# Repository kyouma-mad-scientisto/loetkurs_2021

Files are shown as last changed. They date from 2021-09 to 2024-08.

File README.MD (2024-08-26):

Dieses kleine Badge habe ich 2021 für einen Lötkurs an meiner Hochschule entworfen. Damit sollten die Teilnehmer SMD löten üben. Am Ende konnten sie ihr Werk mit nach Hause nehmen und nach belieben programmieren.
Anlässlich des Girl's Days habe ich in einer späteren Iteration noch einen CH340 ergänzt, damit der Controller ohne extra Hardware programmiert werden kann, es wird nur noch ein Mini-USB Kabel benötigt.

FuldAIno vorn<br />
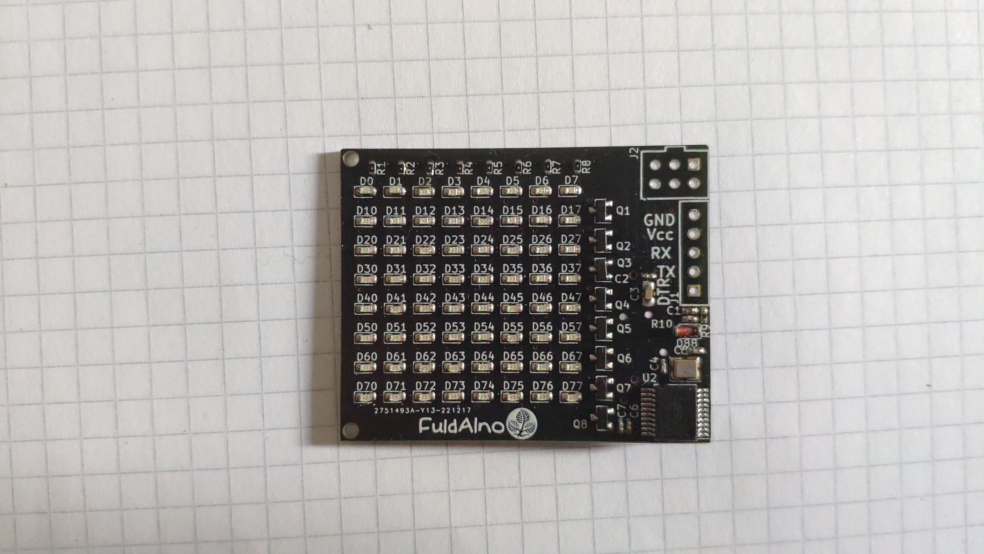
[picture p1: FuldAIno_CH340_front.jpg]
FuldAIno_front


FuldAIno hinten<br />
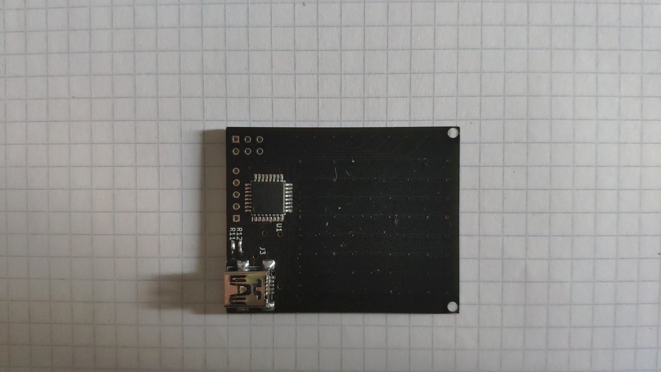
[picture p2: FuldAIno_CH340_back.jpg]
FuldAIno_back


FuldAIno im Betrieb<br />
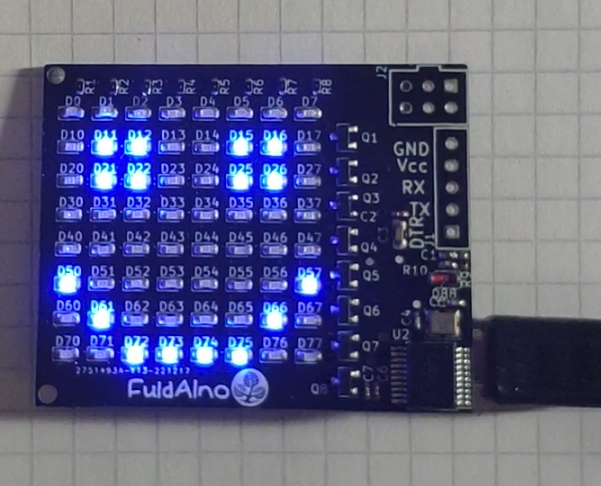
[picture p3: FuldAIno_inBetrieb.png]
FuldAIno_running


IM WEITEREN FOLGT DIE ORIGINALE README.md
###########################################################################################################################################################################################################################

FuldAIno - eine 8x8 LED Matrix gesteuert von einem Atmega328p

Soll FuldAIno nach dem bestücken der Leiterplatte Arduino kompatibel sein, muss zunächst mit einem AVR ISP Flasher, über den 6 pol. ISP Anschluss, der Bootloader auf den Atmega328p gebrannt werden.
Den passenden Bootloader bzw. die passende Bibliothek für das Projekt findet ihr unter: https://github.com/oshlab/Breadboard-Arduino
Bitte zunächst den Anweisungen auf obiger Webseite folgen.
Pinbelegung auf der Platine (Draufsicht).

```
	1  2
       -------
MISO   | o o |  Vcc (5V)
SCK   [  o o |  MOSI
RESET  | o o |  GND
       -------
```

Danach wird ein einfacher USB-Serial Adapter benötigt. Diese findet man sehr günstig bei eBay, aliexpress und co. z.B. unter folgendem Namen: USB zu Serial TTL FT232RL
Hierbei sollte auch auf das Vorhandensein des DTR Pins geachtet werden, dieser wird benötigt, damit die Arduino IDE den Controller zum flashen zurücksetzen kann.
Außerdem empfehle ich gleich einen Adapter zu kaufen, welcher auch für 3,3V Logik geeignet ist, so sind auch zukünftige Projekte mit 3,3V Bauteilen, wie z.B. dem Arduino Pro Mini oder dem ESP32 kein Problem.
Pinbelegung auf der Platine (Draufsicht).

```
        ---
GND     |o|
Vcc(5V) |o|
Rx      |o|
Tx      |o|
DTR     |o|
        ---
```

Den seriellen Adapter entsprechend der obigen Belegung mit dem FuldAIno verbinden (Achtung! TX muss jeweils auf RX), nochmal alles kontrollieren, doppelt hält besser  ;).
Nun den Adapter mit dem PC verbinden, das FuldAIno Demoprojekt öffnen, den korrekten Port und das korrekte Board (Breadboard Arduino (OSHLAB.com) -> Atmega328p (8MHz internal)) auswählen und dann, oben links,
auf den blauen Pfeil klicken (hochladen) und warten, bis der Vorgang abgeschlossen ist.

Hinweise zum Demoprojekt:

Für die regelmäßge Aktualisierung der Anzeige wird der Timer1 des Atmegas beansprucht. Dieser kann also nicht für andere Dinge verwendet werden. Ihr könnt aber die ISR, welche in "ScanLines.ino" ab Zeile 13
beginnt für KURZE Funktionen nutzen, welche regelmäßig ausgeführt werden sollen.
Die Funktion "scanLines()" muss IMMER in der Timer1 ISR ausgeführt werden, sonst findet keine Aktualisierung der Anzeige mehr statt.
Die Datei "ScanLines.ino" am besten garnicht verändern, außer ihr möchtet die LEDs direkt ansteuern, ohne den Framebuffer.

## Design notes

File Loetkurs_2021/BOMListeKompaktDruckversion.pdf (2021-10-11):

Ref | Value | Footprint | Ref | Value | Footprint
C1+C2 | 100nF | 0402 | C1+C2 | 100nF | 0402
C3 | 47µF | 0805 | C3 | 47µF | 0805
D0-D77 | LED | 0603 | D0-D77 | LED | 0603
D88 | Diode | 0805 | D88 | Diode | 0805
J1 | | 1x5 Stiftleiste | J1 | | 1x5 Stiftleiste
J2 | | 2x3 Stiftleiste | J2 | | 2x3 Stiftleiste
J3 | | USB_B_Mini | J3 | | USB_B_Mini
Q1-Q8 | AO3400A | SOT-23 | Q1-Q8 | AO3400A | SOT-23
R1-R8 | 86R6 | 0402 | R1-R8 | 86R6 | 0402
R9 | 1k | 0402 | R9 | 1k | 0402
R10 | 10k | 0402 | R10 | 10k | 0402
U1 | ATmega328P-AU | TQFP | U1 | ATmega328P-AU | TQFP
Ref | Value | Footprint | Ref | Value | Footprint
C1+C2 | 100nF | 0402 | C1+C2 | 100nF | 0402
C3 | 47µF | 0805 | C3 | 47µF | 0805
D0-D77LED | 0603 | D0-D77 | LED | 0603
D88 | Diode | 0805 | D88 | Diode | 0805
J1 | | 1x5 Stiftleiste | J1 | | 1x5 Stiftleiste
J2 | | 2x3 Stiftleiste | J2 | | 2x3 Stiftleiste
J3 | | USB_B_Mini | J3 | | USB_B_Mini
Q1-Q8 | AO3400A | SOT-23 | Q1-Q8 | AO3400A | SOT-23
R1-R8 | 86R6 | 0402 | R1-R8 | 86R6 | 0402
R9 | 1k | 0402 | R9 | 1k | 0402
R10 | 10k | 0402 | R10 | 10k | 0402
U1 | ATmega328P-AU | TQFP | U1 | ATmega328P-AU | TQFP
Ref | Value | Footprint | Ref | Value | Footprint
C1+C2 | 100nF | 0402 | C1+C2 | 100nF | 0402
C3 | 47µF | 0805 | C3 | 47µF | 0805
D0-D77LED | 0603 | D0-D77 | LED | 0603
D88 | Diode | 0805 | D88 | Diode | 0805
J1 | | 1x5 Stiftleiste | J1 | | 1x5 Stiftleiste
J2 | | 2x3 Stiftleiste | J2 | | 2x3 Stiftleiste
J3 | | USB_B_Mini | J3 | | USB_B_Mini
Q1-Q8 | AO3400A | SOT-23 | Q1-Q8 | AO3400A | SOT-23
R1-R8 | 86R6 | 0402 | R1-R8 | 86R6 | 0402
R9 | 1k | 0402 | R9 | 1k | 0402
R10 | 10k | 0402 | R10 | 10k | 0402
U1 | ATmega328P-AU | TQFP | U1 | ATmega328P-AU | TQFP
Ref | Value | Footprint | Ref | Value | Footprint
C1+C2 | 100nF | 0402 | C1+C2 | 100nF | 0402
C3 | 47µF | 0805 | C3 | 47µF | 0805
D0-D77LED | 0603 | D0-D77 | LED | 0603
D88 | Diode | 0805 | D88 | Diode | 0805
J1 | | 1x5 Stiftleiste | J1 | | 1x5 Stiftleiste
J2 | | 2x3 Stiftleiste | J2 | | 2x3 Stiftleiste
J3 | | USB_B_Mini | J3 | | USB_B_Mini
Q1-Q8 | AO3400A | SOT-23 | Q1-Q8 | AO3400A | SOT-23
R1-R8 | 86R6 | 0402 | R1-R8 | 86R6 | 0402
R9 | 1k | 0402 | R9 | 1k | 0402
R10 | 10k | 0402 | R10 | 10k | 0402
U1 | ATmega328P-AU | TQFP | U1 | ATmega328P-AU | TQFP

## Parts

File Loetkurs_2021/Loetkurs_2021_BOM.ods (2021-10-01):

Component Count: | 90
Ref | Value | Footprint
C1 | 100nF | Capacitor_SMD:C_0402_1005Metric_Pad0.74x0.62mm_HandSolder
C2 | 100nF | Capacitor_SMD:C_0402_1005Metric_Pad0.74x0.62mm_HandSolder
C3 | 47µF | Capacitor_SMD:C_0805_2012Metric_Pad1.18x1.45mm_HandSolder
D0 | LED | LED_SMD:LED_0603_1608Metric_Pad1.05x0.95mm_HandSolder
D1 | LED | LED_SMD:LED_0603_1608Metric_Pad1.05x0.95mm_HandSolder
D2 | LED | LED_SMD:LED_0603_1608Metric_Pad1.05x0.95mm_HandSolder
D3 | LED | LED_SMD:LED_0603_1608Metric_Pad1.05x0.95mm_HandSolder
D4 | LED | LED_SMD:LED_0603_1608Metric_Pad1.05x0.95mm_HandSolder
D5 | LED | LED_SMD:LED_0603_1608Metric_Pad1.05x0.95mm_HandSolder
D6 | LED | LED_SMD:LED_0603_1608Metric_Pad1.05x0.95mm_HandSolder
D7 | LED | LED_SMD:LED_0603_1608Metric_Pad1.05x0.95mm_HandSolder
D10 | LED | LED_SMD:LED_0603_1608Metric_Pad1.05x0.95mm_HandSolder
D11 | LED | LED_SMD:LED_0603_1608Metric_Pad1.05x0.95mm_HandSolder
D12 | LED | LED_SMD:LED_0603_1608Metric_Pad1.05x0.95mm_HandSolder
D13 | LED | LED_SMD:LED_0603_1608Metric_Pad1.05x0.95mm_HandSolder
D14 | LED | LED_SMD:LED_0603_1608Metric_Pad1.05x0.95mm_HandSolder
D15 | LED | LED_SMD:LED_0603_1608Metric_Pad1.05x0.95mm_HandSolder
D16 | LED | LED_SMD:LED_0603_1608Metric_Pad1.05x0.95mm_HandSolder
D17 | LED | LED_SMD:LED_0603_1608Metric_Pad1.05x0.95mm_HandSolder
D20 | LED | LED_SMD:LED_0603_1608Metric_Pad1.05x0.95mm_HandSolder
D21 | LED | LED_SMD:LED_0603_1608Metric_Pad1.05x0.95mm_HandSolder
D22 | LED | LED_SMD:LED_0603_1608Metric_Pad1.05x0.95mm_HandSolder
D23 | LED | LED_SMD:LED_0603_1608Metric_Pad1.05x0.95mm_HandSolder
D24 | LED | LED_SMD:LED_0603_1608Metric_Pad1.05x0.95mm_HandSolder
D25 | LED | LED_SMD:LED_0603_1608Metric_Pad1.05x0.95mm_HandSolder
D26 | LED | LED_SMD:LED_0603_1608Metric_Pad1.05x0.95mm_HandSolder
D27 | LED | LED_SMD:LED_0603_1608Metric_Pad1.05x0.95mm_HandSolder
D30 | LED | LED_SMD:LED_0603_1608Metric_Pad1.05x0.95mm_HandSolder
D31 | LED | LED_SMD:LED_0603_1608Metric_Pad1.05x0.95mm_HandSolder
D32 | LED | LED_SMD:LED_0603_1608Metric_Pad1.05x0.95mm_HandSolder
D33 | LED | LED_SMD:LED_0603_1608Metric_Pad1.05x0.95mm_HandSolder
D34 | LED | LED_SMD:LED_0603_1608Metric_Pad1.05x0.95mm_HandSolder
D35 | LED | LED_SMD:LED_0603_1608Metric_Pad1.05x0.95mm_HandSolder
D36 | LED | LED_SMD:LED_0603_1608Metric_Pad1.05x0.95mm_HandSolder
D37 | LED | LED_SMD:LED_0603_1608Metric_Pad1.05x0.95mm_HandSolder
D40 | LED | LED_SMD:LED_0603_1608Metric_Pad1.05x0.95mm_HandSolder
D41 | LED | LED_SMD:LED_0603_1608Metric_Pad1.05x0.95mm_HandSolder
D42 | LED | LED_SMD:LED_0603_1608Metric_Pad1.05x0.95mm_HandSolder
D43 | LED | LED_SMD:LED_0603_1608Metric_Pad1.05x0.95mm_HandSolder
D44 | LED | LED_SMD:LED_0603_1608Metric_Pad1.05x0.95mm_HandSolder
D45 | LED | LED_SMD:LED_0603_1608Metric_Pad1.05x0.95mm_HandSolder
D46 | LED | LED_SMD:LED_0603_1608Metric_Pad1.05x0.95mm_HandSolder
D47 | LED | LED_SMD:LED_0603_1608Metric_Pad1.05x0.95mm_HandSolder
D50 | LED | LED_SMD:LED_0603_1608Metric_Pad1.05x0.95mm_HandSolder
D51 | LED | LED_SMD:LED_0603_1608Metric_Pad1.05x0.95mm_HandSolder
D52 | LED | LED_SMD:LED_0603_1608Metric_Pad1.05x0.95mm_HandSolder
D53 | LED | LED_SMD:LED_0603_1608Metric_Pad1.05x0.95mm_HandSolder
D54 | LED | LED_SMD:LED_0603_1608Metric_Pad1.05x0.95mm_HandSolder
D55 | LED | LED_SMD:LED_0603_1608Metric_Pad1.05x0.95mm_HandSolder
D56 | LED | LED_SMD:LED_0603_1608Metric_Pad1.05x0.95mm_HandSolder
D57 | LED | LED_SMD:LED_0603_1608Metric_Pad1.05x0.95mm_HandSolder
D60 | LED | LED_SMD:LED_0603_1608Metric_Pad1.05x0.95mm_HandSolder
D61 | LED | LED_SMD:LED_0603_1608Metric_Pad1.05x0.95mm_HandSolder
D62 | LED | LED_SMD:LED_0603_1608Metric_Pad1.05x0.95mm_HandSolder
D63 | LED | LED_SMD:LED_0603_1608Metric_Pad1.05x0.95mm_HandSolder
D64 | LED | LED_SMD:LED_0603_1608Metric_Pad1.05x0.95mm_HandSolder
D65 | LED | LED_SMD:LED_0603_1608Metric_Pad1.05x0.95mm_HandSolder
D66 | LED | LED_SMD:LED_0603_1608Metric_Pad1.05x0.95mm_HandSolder
D67 | LED | LED_SMD:LED_0603_1608Metric_Pad1.05x0.95mm_HandSolder
D70 | LED | LED_SMD:LED_0603_1608Metric_Pad1.05x0.95mm_HandSolder
D71 | LED | LED_SMD:LED_0603_1608Metric_Pad1.05x0.95mm_HandSolder
D72 | LED | LED_SMD:LED_0603_1608Metric_Pad1.05x0.95mm_HandSolder
D73 | LED | LED_SMD:LED_0603_1608Metric_Pad1.05x0.95mm_HandSolder
D74 | LED | LED_SMD:LED_0603_1608Metric_Pad1.05x0.95mm_HandSolder
D75 | LED | LED_SMD:LED_0603_1608Metric_Pad1.05x0.95mm_HandSolder
D76 | LED | LED_SMD:LED_0603_1608Metric_Pad1.05x0.95mm_HandSolder
D77 | LED | LED_SMD:LED_0603_1608Metric_Pad1.05x0.95mm_HandSolder
D88 | D | Resistor_SMD:R_0805_2012Metric_Pad1.20x1.40mm_HandSolder
J1 | Conn_01x05_Male | Yves_footprints:Arduino_Pro_Mini_Serial_Connector
J2 | AVR-ISP-6 | Yves_footprints:AVR_ISP_6Pin_Connector
J3 | USB_B_Mini | Connector_USB:USB_Mini-B_Wuerth_65100516121_Horizontal
Q1 | AO3400A | Package_TO_SOT_SMD:SOT-23
Q2 | AO3400A | Package_TO_SOT_SMD:SOT-23
Q3 | AO3400A | Package_TO_SOT_SMD:SOT-23
Q4 | AO3400A | Package_TO_SOT_SMD:SOT-23
Q5 | AO3400A | Package_TO_SOT_SMD:SOT-23
Q6 | AO3400A | Package_TO_SOT_SMD:SOT-23
Q7 | AO3400A | Package_TO_SOT_SMD:SOT-23
Q8 | AO3400A | Package_TO_SOT_SMD:SOT-23
R1 | 86R6 | Resistor_SMD:R_0402_1005Metric_Pad0.72x0.64mm_HandSolder
R2 | 86R6 | Resistor_SMD:R_0402_1005Metric_Pad0.72x0.64mm_HandSolder
R3 | 86R6 | Resistor_SMD:R_0402_1005Metric_Pad0.72x0.64mm_HandSolder
R4 | 86R6 | Resistor_SMD:R_0402_1005Metric_Pad0.72x0.64mm_HandSolder
R5 | 86R6 | Resistor_SMD:R_0402_1005Metric_Pad0.72x0.64mm_HandSolder
R6 | 86R6 | Resistor_SMD:R_0402_1005Metric_Pad0.72x0.64mm_HandSolder
R7 | 86R6 | Resistor_SMD:R_0402_1005Metric_Pad0.72x0.64mm_HandSolder
R8 | 86R6 | Resistor_SMD:R_0402_1005Metric_Pad0.72x0.64mm_HandSolder
R9 | 1k | Resistor_SMD:R_0402_1005Metric_Pad0.72x0.64mm_HandSolder
R10 | 10k | Resistor_SMD:R_0402_1005Metric_Pad0.72x0.64mm_HandSolder
U1 | ATmega328P-AU | Package_QFP:TQFP-32_7x7mm_P0.8mm

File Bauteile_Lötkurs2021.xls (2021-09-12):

WARENKORB
Dies ist keine Rechnung
12-Sep-21 11:34:13
 | Mouser-Nr. | Herst.- Nr. | Hersteller | Kunden-Teilenr | Beschreibung | RoHS | Lebenszyklus | Stückzahl | Preis (EUR) | Gesamtpreis: (EUR)
1 | 821-TS4148RYG | TS4148 RYG | Taiwan Semiconductor |  | Dioden (Allzweck, Leistung, Schaltung) 75V 0.15A SWITCHING DIODE | RoHS-konform |  | 24 | 0,24 € | 5,76 €
2 | 81-GCM155L8EH104KE7D | GCM155L8EH104KE07D | Murata |  | Kondensator aus mehreren Keramikschichten MLCC - SMD/SMT .1UF 50V 10% 0402 | RoHS-konform |  | 24 | 0,059 € | 1,42 €
3 | 743-IN-S63BTG | IN-S63BTG | Inolux |  | Standard-LEDs - SMD True Green LED | RoHS-konform |  | 1000 | 0,077 € | 77,00 €
4 | 640-2665RBHM15STB00A | USB2066-05-RBHM-15-STB-00-00-A | Global Connector Technology (GCT) |  | USB-Stecker Mini B Skt, 5P, Top-SMT, 9.2 Length, R/A, 15u", No Peg, T&R | RoHS-konform | Neues Produkt | 13 | 0,472 € | 6,14 €
5 | 865-XP234N0801TR-G | XP234N0801TR-G | Torex Semiconductor |  | MOSFET General-purpose N-channel MOSFET , 30V / 0.8A / SOT-23 | RoHS-konform | Neues Produkt | 108 | 0,075 € | 8,10 €
6 | 963-JMK212BBJ476MG-T | JMK212BBJ476MG-T | Taiyo Yuden |  | Kondensator aus mehreren Keramikschichten MLCC - SMD/SMT 0805 6.3VDC 47uF 20% X5R | RoHS-konform |  | 24 | 0,205 € | 4,92 €
7 | 71-CRCW04021K00FKEDC | CRCW04021K00FKEDC | Vishay |  | Dickfilmwiderstände - SMD 1/16watt 1Kohms 1% Commercial Use | RoHS: Konform durch Ausnahmegenehmigung |  | 24 | 0,028 € | 0,67 €
8 | 71-CRCW040210K0FKEDC | CRCW040210K0FKEDC | Vishay |  | Dickfilmwiderstände - SMD 1/16watt 10Kohms 1% Commercial Use | RoHS: Konform durch Ausnahmegenehmigung |  | 24 | 0,029 € | 0,70 €
9 | 556-ATMEGA328P-AU | ATMEGA328P-AU | Microchip |  | 8-Bit Mikrocontroller - MCU 32KB In-system Flash 20MHz 1.8V-5.5V | RoHS-konform |  | 13 | 2,02 € | 26,26 €
10 | 667-ERJ-2RKF86R6X | ERJ-2RKF86R6X | Panasonic |  | Dickfilmwiderstände - SMD 0402 86.6ohms 1% AEC-Q200 | RoHS: Konform durch Ausnahmegenehmigung |  | 108 | 0,016 € | 1,73 €
Durch das Absenden Ihrer Bestellung erklären Sie sich mit diesen Geschäftsbedingungen einverstanden. (https://www.mouser.de/saleterms) |  |  |  |  |  |  |  |  | Ware: | 132,70 €
Die Preise sind zum angezeigten Datum und zur Uhrzeit reflektiert. |  |  |  |  |  |  |  |  | Versandkosten: | 0,00 €

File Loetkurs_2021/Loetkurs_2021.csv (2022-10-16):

Source: | /run/media/yves/e825eed3-56a1-4b14-ac8a-89e3fea05e38/VM_Gemeinsam/Entwicklung/Projektdaten_sortiert/eigenes/Layouts + Code/Loetkurs_2021/loetkurs_2021/Loetkurs_2021/Loetkurs_2021.sch
Date: | So 16 Okt 2022 13:24:59 CEST
Tool: | Eeschema (6.0.7)
Generator: | /usr/share/kicad/plugins/bom_csv_grouped_by_value_with_fp.py
Component Count: | 98
Ref | Qnty | Value | Cmp name | Footprint | Description | Vendor
C1, C2, C6, C7, | 4 | 100nF | C | Capacitor_SMD:C_0402_1005Metric_Pad0.74x0.62mm_HandSolder | Unpolarized capacitor
C3, | 1 | 47µF | C | Capacitor_SMD:C_0805_2012Metric_Pad1.18x1.45mm_HandSolder | Unpolarized capacitor
C4, C5, | 2 | 22pF | C | Capacitor_SMD:C_0402_1005Metric_Pad0.74x0.62mm_HandSolder | Unpolarized capacitor
D0, D1, D2, D3, D4, D5, D6, D7, D10, D11, D12, D13, D14, D15, D16, D17, D20, D21, D22, D23, D24, D25, D26, D27, D30, D31, D32, D33, D34, D35, D36, D37, D40, D41, D42, D43, D44, D45, D46, D47, D50, D51, D52, D53, D54, D55, D56, D57, D60, D61, D62, D63, D64, D65, D66, D67, D70, D71, D72, D73, D74, D75, D76, D77, | 64 | LED | LED | LED_SMD:LED_0603_1608Metric_Pad1.05x0.95mm_HandSolder | Light emitting diode
D88, | 1 | D | D | Resistor_SMD:R_0805_2012Metric_Pad1.20x1.40mm_HandSolder | Diode
J1, | 1 | Conn_01x05_Male | Conn_01x05_Male | Yves_footprints:Arduino_Pro_Mini_Serial_Connector | Generic connector, single row, 01x05, script generated (kicad-library-utils/schlib/autogen/connector/)
J2, | 1 | AVR-ISP-6 | AVR-ISP-6 | Yves_footprints:AVR_ISP_6Pin_Connector | Atmel 6-pin ISP connector
J3, | 1 | USB_B_Mini | USB_B_Mini-Connector-Loetkurs_2021-rescue | Connector_USB:USB_Mini-B_Wuerth_65100516121_Horizontal
Q1, Q2, Q3, Q4, Q5, Q6, Q7, Q8, | 8 | AO3400A | AO3400A-Transistor_FET-Loetkurs_2021-rescue | Package_TO_SOT_SMD:SOT-23
R1, R2, R3, R4, R5, R6, R7, R8, | 8 | 86R6 | R | Resistor_SMD:R_0402_1005Metric_Pad0.72x0.64mm_HandSolder | Resistor
R9, R11, R12, | 3 | 1k | R | Resistor_SMD:R_0402_1005Metric_Pad0.72x0.64mm_HandSolder | Resistor
R10, | 1 | 10k | R | Resistor_SMD:R_0402_1005Metric_Pad0.72x0.64mm_HandSolder | Resistor
U1, | 1 | ATmega328P-AU | ATmega328P-AU-MCU_Microchip_ATmega | Package_QFP:TQFP-32_7x7mm_P0.8mm
U2, | 1 | CH340T | CH340T | Package_SO:SSOP-20_5.3x7.2mm_P0.65mm | USB serial converter, UART, SSOP-20
Y1, | 1 | Crystal | Crystal | Crystal:Crystal_SMD_Abracon_ABM8G-4Pin_3.2x2.5mm | Two pin crystal

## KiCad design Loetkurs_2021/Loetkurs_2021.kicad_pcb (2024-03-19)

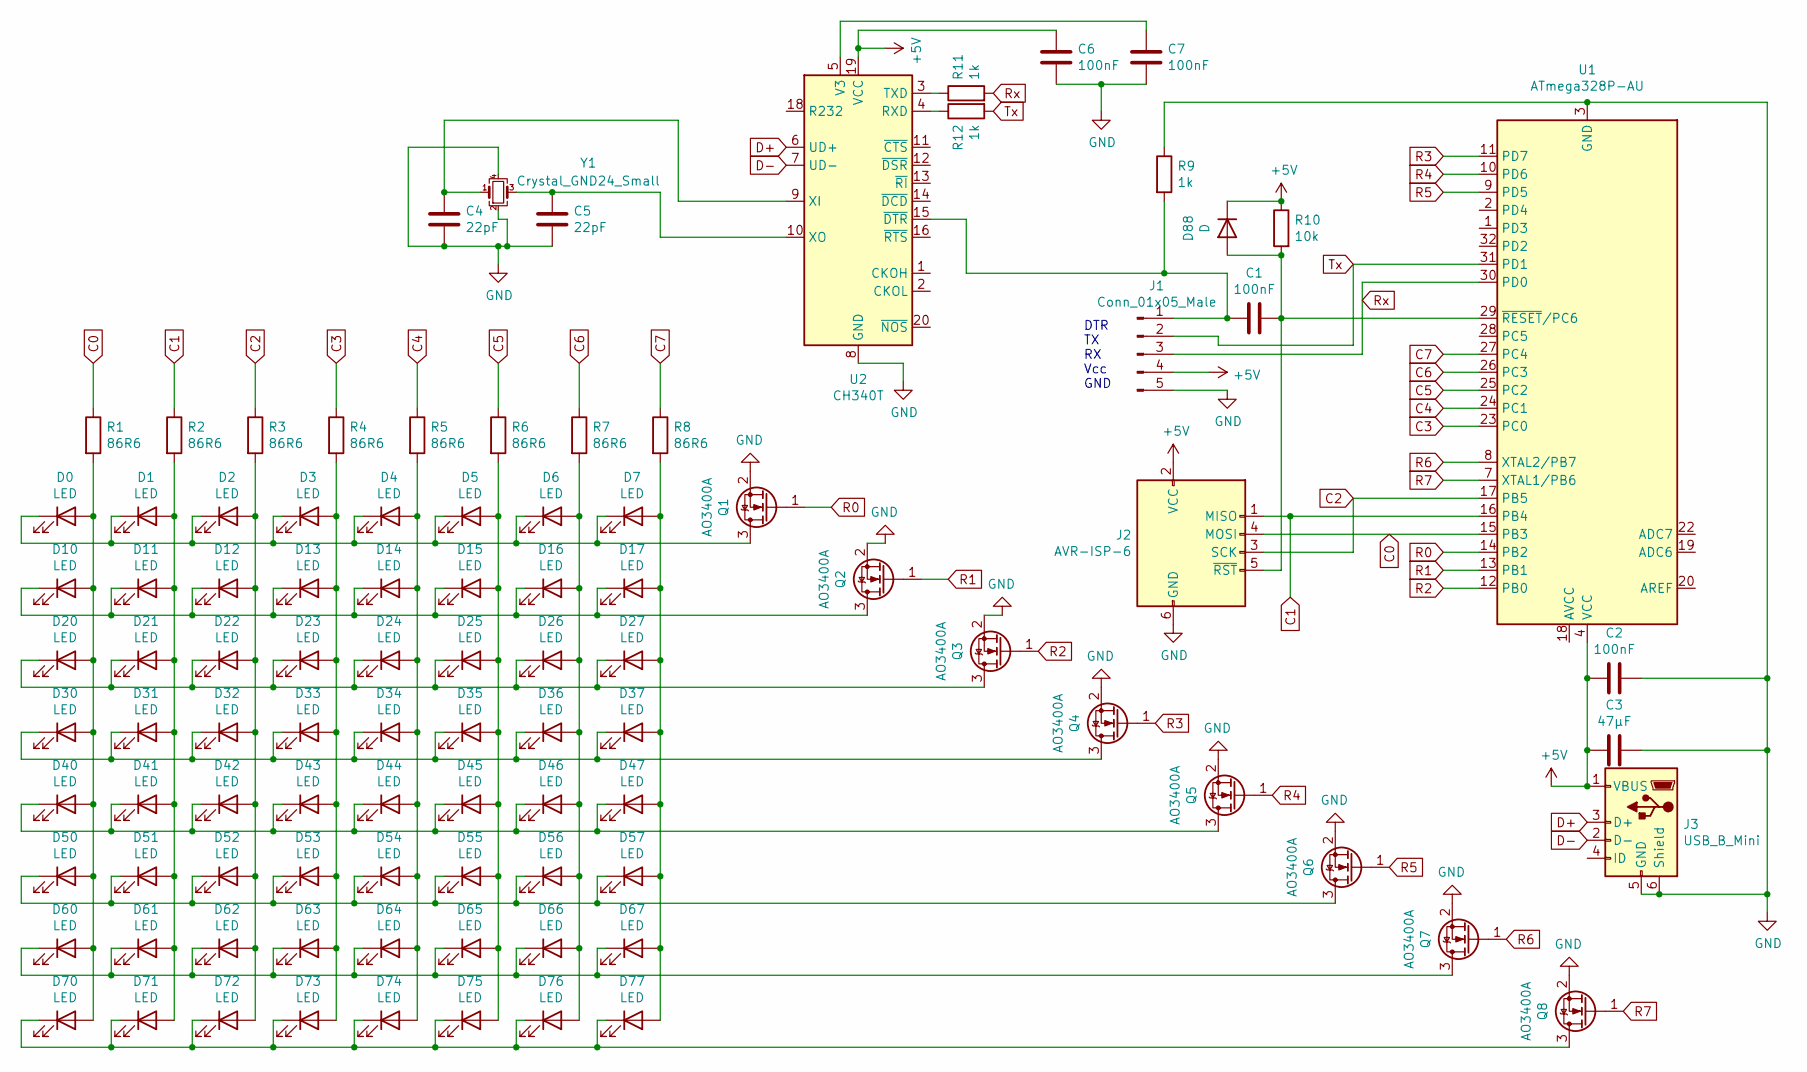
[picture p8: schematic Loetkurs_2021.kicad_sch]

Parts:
C1, C2, C6, C7: 100nF; C_0402_1005Metric_Pad0.74x0.62mm_HandSolder
C3: 47µF; C_0805_2012Metric_Pad1.18x1.45mm_HandSolder
C4, C5: 22pF; C_0402_1005Metric_Pad0.74x0.62mm_HandSolder
D0, D1, D2, D3, D4, D5, D6, D7, D10, D11, D12, D13, D14, D15, D16, D17, D20, D21, D22, D23, D24, D25, D26, D27, D30, D31, D32, D33, D34, D35, D36, D37, D40, D41, D42, D43, D44, D45, D46, D47, D50, D51, D52, D53, D54, D55, D56, D57, D60, D61, D62, D63, D64, D65, D66, D67, D70, D71, D72, D73, D74, D75, D76, D77: LED; LED_0603_1608Metric_Pad1.05x0.95mm_HandSolder
D88: D; D_0805_2012Metric_Pad1.15x1.40mm_HandSolder
J1: Conn_01x05_Male; Arduino_Pro_Mini_Serial_Connector
J2: AVR-ISP-6; AVR_ISP_6Pin_Connector
J3: USB_B_Mini; USB_Mini-B_Wuerth_65100516121_Horizontal
Q1, Q2, Q3, Q4, Q5, Q6, Q7, Q8: AO3400A; SOT-23
R1, R2, R3, R4, R5, R6, R7, R8: 86R6; R_0402_1005Metric_Pad0.72x0.64mm_HandSolder
R9, R11, R12: 1k; R_0402_1005Metric_Pad0.72x0.64mm_HandSolder
R10: 10k; R_0402_1005Metric_Pad0.72x0.64mm_HandSolder
U1: ATmega328P-AU; TQFP-32_7x7mm_P0.8mm
U2: CH340T; SSOP-20_5.3x7.2mm_P0.65mm
Y1: Crystal_GND24_Small; Crystal_SMD_Abracon_ABM8G-4Pin_3.2x2.5mm

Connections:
C0: J2.4 (MOSI), R1.1, U1.15 (PB3)
C1: J2.1 (MISO), R2.1, U1.16 (PB4)
C2: J2.3 (SCK), R3.1, U1.17 (PB5)
C3: R4.1, U1.23 (PC0)
C4: R5.1, U1.24 (PC1)
C5: R6.1, U1.25 (PC2)
C6: R7.1, U1.26 (PC3)
C7: R8.1, U1.27 (PC4)
D+: J3.3 (D+), U2.6 (UD+)
D-: J3.2 (D-), U2.7 (UD-)
GND: C2.1, C3.1, C4.2, C5.2, C6.2, C7.2, J1.5, J2.6 (GND), J3.5 (GND), J3.6 (Shield), Q1.2 (S), Q2.2 (S), Q3.2 (S), Q4.2 (S), Q5.2 (S), Q6.2 (S), Q7.2 (S), Q8.2 (S), R9.1, U1.3 (GND), U1.5 (GND), U1.21 (GND), U2.8 (GND), Y1.2, Y1.4
unnamed: C1.1, J1.1, R9.2, U2.15 (~DTR)
unnamed: C1.2, D88.2 (A), J2.5 (~RST), R10.2, U1.29 (~RESET/PC6)
unnamed: C4.1, U2.9 (XI), Y1.1
unnamed: C5.1, U2.10 (XO), Y1.3
unnamed: C7.1, U2.5 (V3)
unnamed: D0.1 (K), D1.1 (K), D2.1 (K), D3.1 (K), D4.1 (K), D5.1 (K), D6.1 (K), D7.1 (K), Q1.3 (D)
unnamed: D0.2 (A), D10.2 (A), D20.2 (A), D30.2 (A), D40.2 (A), D50.2 (A), D60.2 (A), D70.2 (A), R1.2
unnamed: D1.2 (A), D11.2 (A), D21.2 (A), D31.2 (A), D41.2 (A), D51.2 (A), D61.2 (A), D71.2 (A), R2.2
unnamed: D10.1 (K), D11.1 (K), D12.1 (K), D13.1 (K), D14.1 (K), D15.1 (K), D16.1 (K), D17.1 (K), Q2.3 (D)
unnamed: D2.2 (A), D12.2 (A), D22.2 (A), D32.2 (A), D42.2 (A), D52.2 (A), D62.2 (A), D72.2 (A), R3.2
unnamed: D3.2 (A), D13.2 (A), D23.2 (A), D33.2 (A), D43.2 (A), D53.2 (A), D63.2 (A), D73.2 (A), R4.2
unnamed: D4.2 (A), D14.2 (A), D24.2 (A), D34.2 (A), D44.2 (A), D54.2 (A), D64.2 (A), D74.2 (A), R5.2
unnamed: D5.2 (A), D15.2 (A), D25.2 (A), D35.2 (A), D45.2 (A), D55.2 (A), D65.2 (A), D75.2 (A), R6.2
unnamed: D6.2 (A), D16.2 (A), D26.2 (A), D36.2 (A), D46.2 (A), D56.2 (A), D66.2 (A), D76.2 (A), R7.2
unnamed: D7.2 (A), D17.2 (A), D27.2 (A), D37.2 (A), D47.2 (A), D57.2 (A), D67.2 (A), D77.2 (A), R8.2
unnamed: D20.1 (K), D21.1 (K), D22.1 (K), D23.1 (K), D24.1 (K), D25.1 (K), D26.1 (K), D27.1 (K), Q3.3 (D)
unnamed: D30.1 (K), D31.1 (K), D32.1 (K), D33.1 (K), D34.1 (K), D35.1 (K), D36.1 (K), D37.1 (K), Q4.3 (D)
unnamed: D40.1 (K), D41.1 (K), D42.1 (K), D43.1 (K), D44.1 (K), D45.1 (K), D46.1 (K), D47.1 (K), Q5.3 (D)
unnamed: D50.1 (K), D51.1 (K), D52.1 (K), D53.1 (K), D54.1 (K), D55.1 (K), D56.1 (K), D57.1 (K), Q6.3 (D)
unnamed: D60.1 (K), D61.1 (K), D62.1 (K), D63.1 (K), D64.1 (K), D65.1 (K), D66.1 (K), D67.1 (K), Q7.3 (D)
unnamed: D70.1 (K), D71.1 (K), D72.1 (K), D73.1 (K), D74.1 (K), D75.1 (K), D76.1 (K), D77.1 (K), Q8.3 (D)
unnamed: R11.1, U2.3 (TXD)
unnamed: R12.1, U2.4 (RXD)
R0: Q1.1 (G), U1.14 (PB2)
R1: Q2.1 (G), U1.13 (PB1)
R2: Q3.1 (G), U1.12 (PB0)
R3: Q4.1 (G), U1.11 (PD7)
R4: Q5.1 (G), U1.10 (PD6)
R5: Q6.1 (G), U1.9 (PD5)
R6: Q7.1 (G), U1.8 (XTAL2/PB7)
R7: Q8.1 (G), U1.7 (XTAL1/PB6)
Rx: J1.3, R11.2, U1.30 (PD0)
Tx: J1.2, R12.2, U1.31 (PD1)

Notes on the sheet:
DTR TX RX Vcc GND

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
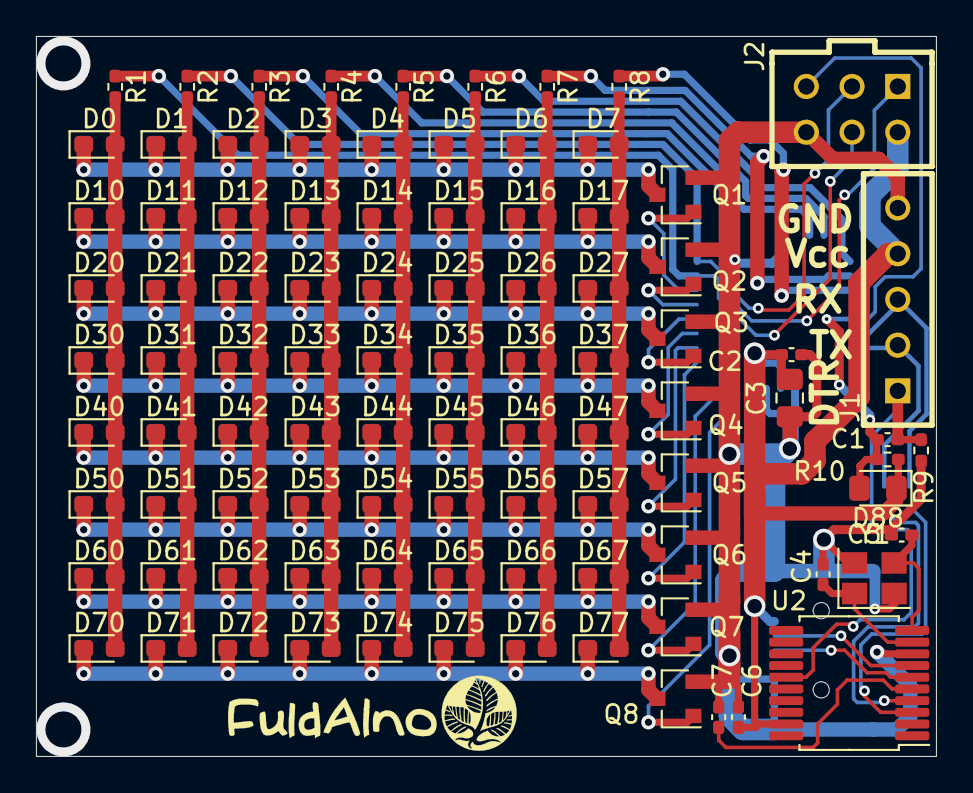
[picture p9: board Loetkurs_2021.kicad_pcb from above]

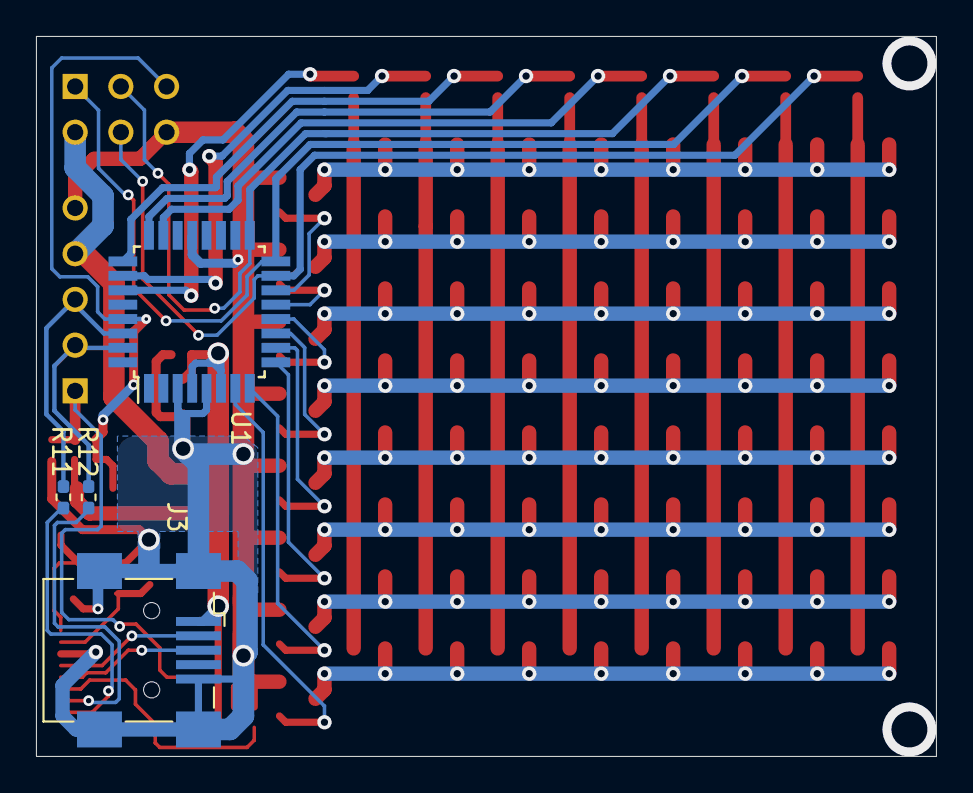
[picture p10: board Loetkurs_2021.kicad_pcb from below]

Board: 2 copper layers, 50.0 x 40.0 mm, 98 parts (4 on the bottom side), 45 nets.

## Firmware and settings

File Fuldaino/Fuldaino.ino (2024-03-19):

/*
 * Code fuer Badget zum Loetkurs an der HS-Fulda am Fachbereich AI
 * 
 * 8x8 LED Matrix
 * Atmega328p mit internem 8MHz Takt
 * 
 * benoetigt die "Breadboard Arduino" Library
 * siehe dazu:
 * https://github.com/oshlab/Breadboard-Arduino
 * 
 *
 * von Yves E.
 */
#include<avr/interrupt.h>
#include <avr/io.h>
#include <util/delay.h>
#include <avr/pgmspace.h>

const char testText[] = {"FuldAIno Girl's Day 2023  "};

const uint16_t AnimationTimeout = 1000;

void setup() 
{
  Serial.begin(115200);
  Serial.println("Start FuldAIno");
  initScanning();
  pushText(testText, sizeof(testText)-1);
}

void loop()
{
  static bool invertieren = false;
 
  invertDisplay(invertieren);
  Serial.println("Display invertieren = " + String(invertieren));
   
  //Demomuster
  Serial.println("Start Demo 1");
  for(uint8_t k=0; k<2; k++) {
    for(uint8_t i=0; i < 8; i++) {
      for(uint8_t j=0; j < 8; j++){
        if(getPixel(j,i)) {
          clearPixel(j,i);
        } else {setPixel(j,i);}
        delay(50);
      }
    }
  }
  //Herz
  Serial.println("Herz");
  setPixel(1,0);
  setPixel(2,0);
  setPixel(5,0);
  setPixel(6,0);
  setPixel(0,1);
  setPixel(3,1);
  setPixel(4,1);
  setPixel(7,1);
  setPixel(0,2);
  setPixel(7,2);
  setPixel(0,3);
  setPixel(7,3);
  setPixel(1,4);
  setPixel(6,4);
  setPixel(2,5);
  setPixel(5,5);
  setPixel(3,6);
  setPixel(4,6);

  delay(3000);
  clearDisplay();
  for(uint8_t i=0; i<2; i++)
  {
    //Smiley
    //traurig
    Serial.println("trauriges Smiley");
    setPixel(1,1);
    setPixel(6,1);
    setPixel(2,1);
    setPixel(5,1);
    setPixel(1,2);
    setPixel(6,2);
    setPixel(2,2);
    setPixel(5,2);
    setPixel(2,5);
    setPixel(3,5);
    setPixel(4,5);
    setPixel(5,5);
    setPixel(1,6);
    setPixel(6,6);
    setPixel(0,7);
    setPixel(7,7);
    delay(AnimationTimeout);
    clearDisplay();
    //neutral
    Serial.println("neutrales Smiley");
    setPixel(1,1);
    setPixel(6,1);
    setPixel(2,1);
    setPixel(5,1);
    setPixel(1,2);
    setPixel(6,2);
    setPixel(2,2);
    setPixel(5,2);
    setPixel(1,5);
    setPixel(2,5);
    setPixel(3,5);
    setPixel(4,5);
    setPixel(5,5);
    setPixel(6,5);
    delay(AnimationTimeout);
    clearDisplay();
    //froh
    Serial.println("frohes Smiley");
    setPixel(1,1);
    setPixel(6,1);
    setPixel(2,1);
    setPixel(5,1);
    setPixel(1,2);
    setPixel(6,2);
    setPixel(2,2);
    setPixel(5,2);
    setPixel(0,5);
    setPixel(7,5);
    setPixel(1,6);
    setPixel(6,6);
    setPixel(2,7);
    setPixel(3,7);
    setPixel(4,7);
    setPixel(5,7);
    delay(AnimationTimeout);
    clearDisplay();
  }
  clearDisplay();
  //Scrolltext
  Serial.print("Start Textscrolling: ");
  Serial.println(testText);
  while(!scrollMessage()) { 
  }
  invertieren = !invertieren;
}

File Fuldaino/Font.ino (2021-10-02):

// Array holding arrays of 5 Bytes for each representation of an ASCII character, stored in flash 
const char characters[96][5] PROGMEM = { 
 {0b00000000,0b00000000,0b00000000,0b00000000,0b00000000}, // space
 {0b00000000,0b00000000,0b01001111,0b00000000,0b00000000}, // !
 {0b00000000,0b00000111,0b00000000,0b00000111,0b00000000}, // "
 {0b00010100,0b01111111,0b00010100,0b01111111,0b00010100}, // #
 {0b00100100,0b00101010,0b01111111,0b00101010,0b00010010}, // $
 {0b00100011,0b00010011,0b00001000,0b01100100,0b01100010}, // %
 {0b00110110,0b01001001,0b01010101,0b00100010,0b01010000}, // &
 {0b00000000,0b00000101,0b00000011,0b00000000,0b00000000}, // '
 {0b00000000,0b00011100,0b00100010,0b01000001,0b00000000}, // (
 {0b00000000,0b01000001,0b00100010,0b00011100,0b00000000}, // )
 {0b00010100,0b00001000,0b00111110,0b00001000,0b00010100}, // *
 {0b00001000,0b00001000,0b00111110,0b00001000,0b00001000}, // +
 {0b00000000,0b01010000,0b00110000,0b00000000,0b00000000}, // ,
 {0b00001000,0b00001000,0b00001000,0b00001000,0b00001000}, // -
 {0b00000000,0b01100000,0b01100000,0b00000000,0b00000000}, // .
 {0b00100000,0b00010000,0b00001000,0b00000100,0b00000010}, // /
 {0b00111110,0b01010001,0b01001001,0b01000101,0b00111110}, // 0
 {0b00000000,0b01000010,0b01111111,0b01000000,0b00000000}, // 1
 {0b01000010,0b01100001,0b01010001,0b01001001,0b01000110}, // 2
 {0b00100001,0b01000001,0b01000101,0b01001011,0b00110001}, // 3
 {0b00011000,0b00010100,0b00010010,0b01111111,0b00010000}, // 4
 {0b00100111,0b01000101,0b01000101,0b01000101,0b00111001}, // 5 
 {0b00111100,0b01001010,0b01001001,0b01001001,0b00110000}, // 6
 {0b00000011,0b01110001,0b00001001,0b00000101,0b00000011}, // 7
 {0b00110110,0b01001001,0b01001001,0b01001001,0b00110110}, // 8
 {0b00000110,0b01001001,0b01001001,0b00101001,0b00011110}, // 9
 {0b00000000,0b01101100,0b01101100,0b00000000,0b00000000}, // :
 {0b00000000,0b01010110,0b00110110,0b00000000,0b00000000}, // ;
 {0b00001000,0b00010100,0b00100010,0b01000001,0b00000000}, // <
 {0b00010100,0b00010100,0b00010100,0b00010100,0b00010100}, // =
 {0b00000000,0b01000001,0b00100010,0b00010100,0b00001000}, // >
 {0b00000010,0b00000001,0b01010001,0b00001001,0b00000110}, // ?
 {0b00110010,0b01001001,0b01111001,0b01000001,0b00111110}, // @
 {0b01111110,0b00010001,0b00010001,0b00010001,0b01111110}, // A
 {0b01111111,0b01001001,0b01001001,0b01001001,0b00111110}, // B
 {0b00111110,0b01000001,0b01000001,0b01000001,0b00100010}, // C
 {0b01111111,0b01000001,0b01000001,0b01000001,0b00111110}, // D
 {0b01111111,0b01001001,0b01001001,0b01001001,0b01001001}, // E
 {0b01111111,0b00001001,0b00001001,0b00001001,0b00000001}, // F
 {0b00111110,0b01000001,0b01001001,0b01001001,0b00111010}, // G
 {0b01111111,0b00001000,0b00001000,0b00001000,0b01111111}, // H
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
};

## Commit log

2021-09-11 bezeichnungen am Panel geaendert
    [Loetkurs_2021.kicad_pcb, Loetkurs_2021.sch]
2021-09-12 kleine Aenderungen am Schaltplan (Werte)
    [Bauteile_Lötkurs2021.xls, Kostenaufstellung_Loetkurs2021.ods, Loetkurs_2021.kicad_pcb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]
2021-09-12 Benennung LEDs geändert
    [Loetkurs_2021.kicad_pcb, Loetkurs_2021.sch]
2021-09-12 doppelte Bezeichnungen gefixt
    [Loetkurs_2021.kicad_pcb, Loetkurs_2021.sch]
2021-09-12 Projekteinstellungen aktualisiert
    [Loetkurs_2021.kicad_pcb]
2021-09-30 BOM ergaenzt
2021-09-30 Kompakte BOM-Liste hinzugefügt
    [BOMListeKompakt.csv]
2021-10-01 erste Demo
    [Loetkurs_2021_BOM.ods]
2021-10-04 Problem mit Bitoperationen gefixt
    [ScanLines.ino]
2021-10-08 README ergaenzt
    [Kostenaufstellung_Loetkurs2021.ods]
2021-10-11 BOM-Liste aktualisiert
    [BOMListeKompakt.csv]
2021-11-26 ch340 hinzugefuegt
    [Loetkurs_2021.sch]
2021-11-27 fast fertig
    [Loetkurs_2021.kicad_pcb, Loetkurs_2021.sch]
2022-10-11 FuldAIno mit CH340 fertiggestellt
    [Loetkurs_2021.kicad_pcb]
2022-10-16 Footprint einer Diode korrigiert
    [Loetkurs_2021.csv, Loetkurs_2021.kicad_sch]
2024-03-19 files added
    [Loetkurs_2021.kicad_pcb, Loetkurs_2021.kicad_sch]
